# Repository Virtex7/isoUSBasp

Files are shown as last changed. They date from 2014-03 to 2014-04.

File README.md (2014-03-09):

isoUSBasp
=========

3kV isolated USBasp-compatible Atmel AVR8 USB programmer

description in German Language:

3kV Dauerlast-isolierter USBasp mit Leistungstreibern am Ausgang

diese Version des bekannten Atmel-Programmiergeräts USBasp von Thomas Fischl
enthält ein paar zusätzliche Fähigkeiten:

- überall LEDs
- LEDs statt Zenerdioden am USB-Port (schöner!)
- galvanisch isolierter ISP-Port
- galvanisch getrennte Target-Supplyfunktion bis 200mA in 3,3 und 5V
- automatische Einstellung der Programmierspannung
- Leistungstreiber an den Programmierpins mit je +-70mA dauerkurzschlussfest
- Schmitt-Trigger-Eingänge mit Signalrückgewinnung
- per Schalter einstellbare slowSCK-Funktionalität für 128kHz-Targets

effektiv soll dieser Programmieradapter überall eingesetzt werden, auch wenn das Target
auf einer viel höheren Spannungsebene liegt, als der zur Programmierung eingesetzte PC.
Auch werden durch eine Massetrennung Masseschleifen und damit bedingte Fehlerströme
vermieden, die zur Beschädigung des PCs und des Programmiergeräts führen können.

Desweiteren ist jeder Programmierpin mit Schutzbeschaltung gegen Überspannung,
Dauerkurzschluss und in Grenzen gegen Rückspeisung geschützt.

Die Programmierspannung stellt sich automatisch ein, wenn am Vref-Pin des ISP-Anschlusses
eine Spannung anliegt. Default ist 3,3V, auch wenn keine Spannung am Vref-Pin liegt.
Umschaltgrenze ist 3,6V, dabei wird dann auf 5V ISP-Spannung umgeschaltet.

Es ist auch möglich den Vref-Anschluss zu bestromen, also das Target mit Strom zu
versorgen. Maximalstrom ist dabei 200mA bei 5V und ca 300mA bei 3,3V, durch einen
Widerstand dauerhaft kurzschlussfest. (dabei bricht die Spannung zusammen)

Hardware:

Schaltplan und Layout und alle nötigen Libs wurden entweder von mir erstellt oder sind
Teil des OpenSource-Projekts KiCad (EDA)
Ich empfehle die Verwendung einer selbst kompilierten Version von KiCad, da diese die
aktuellste Version ist und KiCad momentan recht schnell entwickelt wird.

Software:

Das Produkt ist zu fast 100% kompatibel zur FISCHL-USBasp-Software, dafür wurden ein paar
Inverter extra verbaut, das hätte man auch in Software machen können.
Allerdings muss das Relais an PC3 nach erfolgter Anmeldung am USB angeschaltet werden,
das ist und wird die einzige Modifikation an der Software.

Daher verweise ich auch auf die Homepage von Thomas Fischl:
http://www.fischl.de/usbasp/

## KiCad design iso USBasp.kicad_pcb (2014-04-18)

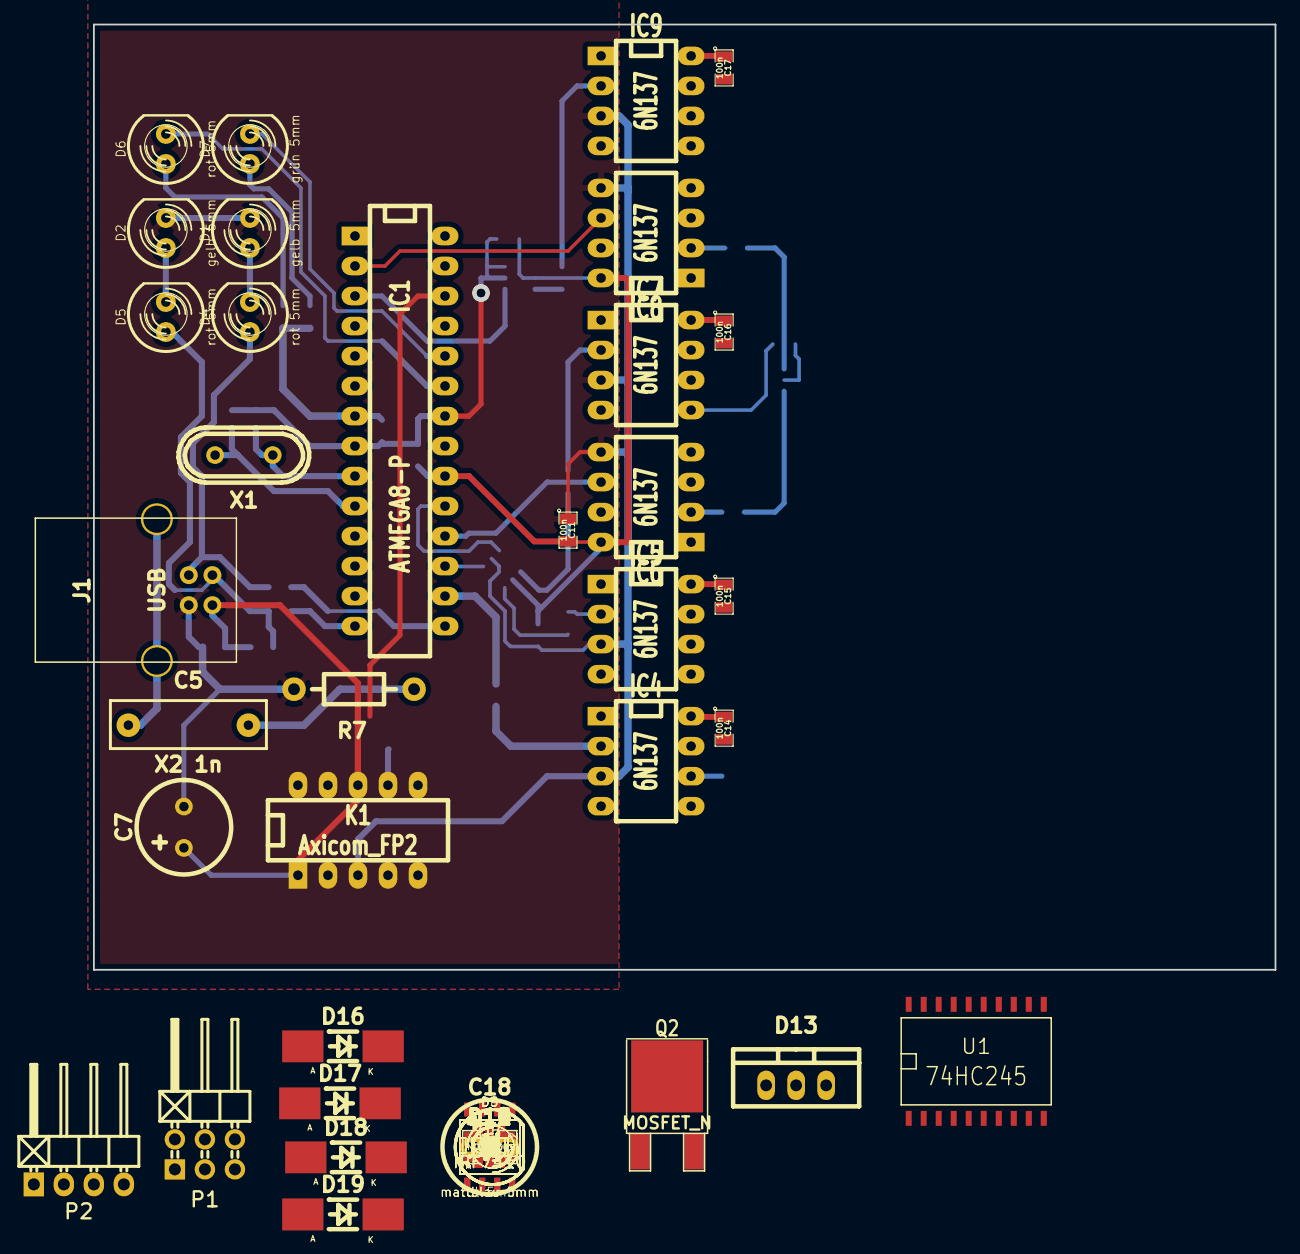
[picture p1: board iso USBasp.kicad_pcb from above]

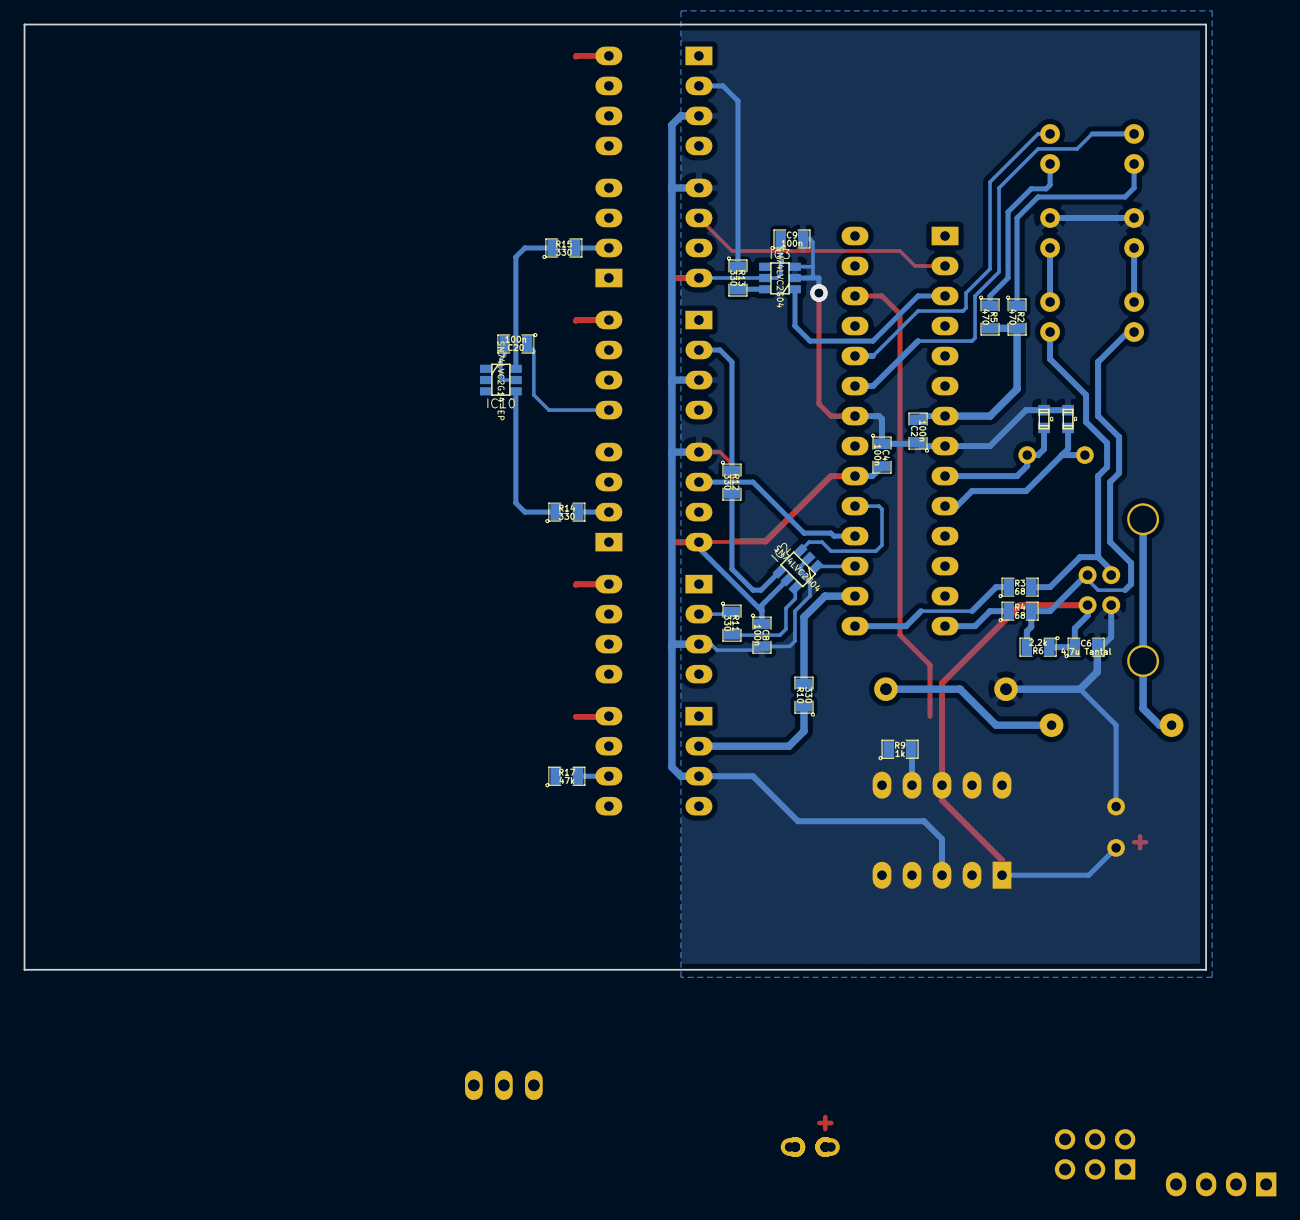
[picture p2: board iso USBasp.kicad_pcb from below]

Board: 2 copper layers, 100.0 x 80.0 mm, 95 parts (24 on the bottom side), 62 nets.

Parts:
C1, C3: 22p; c_0603
C2, C4, C8, C9, C10, C11, C12, C13, C14, C15, C16, C17, C20, C21, C22, C23, C24: 100n; SM0805
C5: X2 1n; Capacitor13x4RM10
C6: 4,7u Tantal; SM0805
C7, C18: 100u; Elko_vert_DM8_RM3-5
C19, C25: 10u; SM0805
D1, D2: gelb 5mm; LED-5MM
D3, D4, D5, D6: rot 5mm; LED-5MM
D7: grün 5mm; LED-5MM
D8, D9: mattblau 5mm; LED-5MM
D10: 3,6V; Diode-MiniMELF_Standard
D11, D12, D14: 5,1V; Diode-MiniMELF_Standard
D13: com. kath.; TO-220_Neutral123_Vertical
D15: 1n4148; Diode-MiniMELF_Standard
D16: 30V 1A; Diode-MELF_Handsoldering
D17, D18, D19: P6KE6,8A; Diode-MELF_Handsoldering
IC1: ATMEGA8-P; DIP-28__300_ELL
IC2, IC3: SN74LVC2G04; SOT23_6
IC4, IC5, IC6, IC7, IC8, IC9: 6N137; DIP-8__300_ELL
IC10: SN74LVC2G14-EP; SOT23_6
IC11: MCP16301; SOT23_6
IC12: TLV3501; SOT23_6
J1: USB; USB_B
K1: Axicom_FP2; DIP-10__300_ELL
L2: 15uH; SM1210
P1: CONN_3X2; Pin_Header_Angled_2x03
P2: CONN_4; Pin_Header_Angled_1x04
Q2: MOSFET_N; DPAKGDS
Q5, Q7: IRF7410; SO8N
R1, R2, R5: 470; SM0805
R3, R4: 68; SM0805
R6: 2,2k; SM0805
R7: 1M THT; Resistor_Horizontal_RM10mm
R8, R9, R18, R24, R27: 1k; SM0805
R10, R11, R12, R13, R14, R15: 330; SM0805
R16, R19: 10; SM0805
R17, R21, R23, R25, R26: 47k; SM0805
R20: 1M; SM0805
R22, R29: 10k; SM0805
R28: 31,2k; SM0805
U1: 74HC245; SO20L
X1: 12MHz; Crystal_HC49-U_Vertical

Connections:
+3.3V: C24.1, C25.1, D15.1, L2.1, R28.1
+5V: C13.1, C14.1, C15.1, C16.1, C17.1, C18.1, C19.1, C23.2, IC4.8, IC5.8, IC7.8, IC9.8, IC11.4, IC12.4, R18.2, R22.1, R24.2, R27.1
/DCDC_on: IC1.26, R8.1
/ISP_MISO: IC1.18, IC6.6
/ISP_MOSI: IC1.17, IC2.1
/ISP_RESET: IC1.16, R10.2
/ISP_SCK: IC1.19, IC2.3
/RX: IC1.2, IC8.6, P2.2, R26.1
/TX: D19.2, IC1.3, IC3.1, P2.3, U1.11, U1.12
/miso: P1.1, R25.1
/mosi: D18.2, P1.4, U1.13, U1.14, U1.15
/reset: P1.5, R16.1
/sck: D17.2, P1.3, U1.16, U1.17, U1.18
/slowSCK: D3.2, IC1.25
/targ_vcc: P1.2, P2.1, R19.1, R20.1, R21.2
AGND: C1.2, C2.1, C3.2, C4.1, C6.2, C7.2, C8.2, C9.2, C10.1, C11.1, C13.2, C14.2, C15.2, C16.2, C17.2, C18.2, C19.2, C20.1, C22.2, C23.1, C24.2, C25.2, D1.2, D2.2, D9.2, D10.1, D11.1, D12.1, D14.1, D16.1, D17.1, D18.1, D19.1, IC1.8, IC1.22, IC2.2, IC3.2, IC3.3, IC4.3, IC4.5, IC5.3, IC5.5, IC6.3, IC6.5, IC7.3, IC7.5, IC8.3, IC8.5, IC9.3, IC9.5, IC10.2, IC11.2, IC12.2, IC12.6, J1.4, K1.3, P1.6, P2.4, Q2.S, R7.2, R17.1, R20.2, R29.2, U1.10
unnamed: C1.1, IC1.10, X1.2
unnamed: C3.1, IC1.9, X1.1
unnamed: C5.1, J1.5, J1.6
unnamed: C5.2, R7.1
unnamed: C12.1, D8.2, K1.4
unnamed: C12.2, K1.7, R9.2
unnamed: C21.1, D15.2, IC11.1
unnamed: C21.2, D16.2, IC11.5, L2.2
unnamed: D1.1, D4.2
unnamed: D2.1, D5.2
unnamed: D3.1, R1.2
unnamed: D4.1, J1.3, R3.2
unnamed: D5.1, J1.2, R4.2, R6.2
unnamed: D6.1, R2.1
unnamed: D6.2, IC1.23
unnamed: D7.1, R5.1
unnamed: D7.2, IC1.24
unnamed: D8.1, R9.1
unnamed: D9.1, R18.1
unnamed: D10.2, IC12.1, R22.2
unnamed: D11.2, IC12.3, R21.1
unnamed: D12.2, IC10.1, R25.2
unnamed: D13.2, R24.1
unnamed: D13.3, R27.2
unnamed: D14.2, IC10.3, R26.2
unnamed: IC1.14, R4.1
unnamed: IC1.4, IC1.15, R3.1
unnamed: IC2.4, R12.2
unnamed: IC2.6, R11.2
unnamed: IC3.6, R13.2
unnamed: IC4.2, R10.1
unnamed: IC4.6, Q2.G, R17.2
unnamed: IC5.2, R11.1
unnamed: IC5.6, U1.5, U1.6, U1.7
unnamed: IC6.2, R14.2
unnamed: IC7.2, R12.1
unnamed: IC7.6, U1.2, U1.3, U1.4
unnamed: IC8.2, R15.2
unnamed: IC9.2, R13.1
unnamed: IC9.6, U1.8, U1.9
unnamed: IC10.4, R14.1
unnamed: IC10.6, R15.1
unnamed: IC11.3, R28.2, R29.1
unnamed: Q2.D, R16.2
unnamed: R23.1, U1.19
VCOM: C2.2, C4.2, C6.1, C7.1, C8.1, C9.1, C10.2, C11.2, C20.2, C22.1, IC1.7, IC1.20, IC2.5, IC3.5, IC6.8, IC8.8, IC10.5, J1.1, K1.1, K1.8, R1.1, R2.2, R5.2, R6.1, R23.2, U1.1, U1.20

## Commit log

2014-03-09 Update .gitignore
    change to an KiCad-Compatible Version...
2014-03-09 Schaltplan-Projekt, Plan ist an sich fertig, ggf noch Fehlerkorrekturen nötig und die zwei mosfet-Typen müssen noch spezifiziert werden.
    [iso USBasp.sch]
2014-03-09 zuordunugsdateien schaltplan -> footprints dazu, aber noch nicht fertig. + noch ein paar Änderungen am Schaltplan
    [iso USBasp.sch]
2014-04-05 neue Footprints für MOSFETs und Schalter dazugefügt.
    [iso USBasp.sch]
2014-04-18 Anfang des Layouts, der USB-verbundene Teil ist schon fast fertig. es fehlen noch die Footprints von Schaltern und dem TRACO-DCDC-Wandler
    [iso USBasp.kicad_pcb, iso USBasp.sch]
